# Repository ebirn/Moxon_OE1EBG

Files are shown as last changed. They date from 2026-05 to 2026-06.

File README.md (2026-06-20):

# Moxon antenna kit
by OE1EBG

## Interactive calculator



An interactive Jupyter notebook for Moxon rectangle dimensions and visualization is available at [`notebooks/interactive_moxon_calculator.ipynb`](notebooks/interactive_moxon_calculator.ipynb).

The notebook includes the theory note from [`notebooks/moxon_theory.md`](notebooks/moxon_theory.md), presets for 2 m and 70 cm, conductor diameter and velocity factor controls, dimension tables, and scaled geometry plots.

## Tuning guide

Structured build and tuning instructions are available in [`TUNING.md`](TUNING.md). The guide starts from the printed T-pieces, pipes, wire, and an antenna analyzer such as a NanoVNA or RigExpert Stick, then walks through iterative Moxon-specific tuning.

The tuning protocol notebook [`notebooks/moxon_tuning_protocol.ipynb`](notebooks/moxon_tuning_protocol.ipynb) provides a form for logging iterative measurements to CSV sessions under `notebooks/data/`. Notebook cell outputs are cleared by the repository hooks, so CSV files are the persistent tuning records and can be saved/restored independently.

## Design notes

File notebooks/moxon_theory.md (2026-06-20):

# Moxon Rectangle Antenna Theory

The Moxon rectangle is a compact, directional, two-element antenna invented by Les Moxon, G6XN. It behaves like a folded two-element Yagi: one element is driven from the feed line, and the second element is a parasitic reflector. The element ends are bent toward each other, so the antenna occupies less space than a straight two-element Yagi while retaining useful gain, a broad forward lobe, and a strong front-to-back ratio.

This kit is aimed mainly at the 70 cm and 2 m amateur radio bands. At those frequencies the dimensions are physically manageable, but small construction errors are also a larger fraction of a wavelength. That makes geometry, conductor diameter, feed layout, and mounting details important.

## Geometry

A conventional Moxon rectangle is described with five practical dimensions:

| Symbol | Meaning |
| --- | --- |
| `A` | Long horizontal span of the driven element side |
| `B` | Folded driven-element tail length at each end |
| `C` | Gap between the driven tail and reflector tail |
| `D` | Folded reflector tail length at each end |
| `E` | Spacing between the driven-element side and reflector side |

The driven element is split at the middle for the feed point. The reflector is continuous and is not electrically connected to the feed line. The close end coupling through the `C` gaps is what makes the Moxon different from a simple bent dipole and reflector pair.

## Build-kit H-frame

This kit uses two T-pieces to hold the antenna in an H-shaped frame. Four equal outer pipes support the driven-element and reflector wires, and one center pipe sets the distance between the driven element and reflector.

The notebook derives these mechanical pipe dimensions from the electrical Moxon dimensions:

```text
outer_pipe_length = A / 2 - radiator_pipe_offset
center_pipe_length = E - center_pipe_offset
```

The offsets account for socket depth, printed part geometry, wire attachment position, or any other mechanical distance between the pipe end and the actual electrical wire position. They are defined globally in the notebook as `RADIATOR_PIPE_OFFSET_MM` and `CENTER_PIPE_OFFSET_MM`, so a kit-specific value can be set once and reused for every frequency.

## Why the Moxon works

The driven element produces the primary radiation. The reflector is placed behind it and is slightly longer in effective electrical length. Because the reflector is parasitic, current is induced in it by the field from the driven element. The induced current has a phase relationship that reinforces radiation in the forward direction and cancels part of the radiation toward the rear.

In a straight two-element Yagi, the reflector is normally behind the driven element with an open air spacing. In the Moxon, the ends of both elements are folded toward each other. This changes the mutual coupling. The folded ends add capacitance and make the antenna shorter across the boom direction. The result is a compact rectangle with impedance often close enough to 50 ohms for direct coax feed when dimensions are chosen well.

## Electrical length and wavelength

The free-space wavelength is:

```text
lambda = c / f
```

where `c` is the speed of light and `f` is the design frequency. For quick radio work:

```text
lambda_m = 299.792458 / frequency_MHz
```

Real conductors do not behave exactly like infinitely thin wires in free space. Conductor diameter, insulation, bends, nearby plastic or metal, and the feed connection all shift resonance. A velocity factor can be used as a simple build correction, but final tuning should still be done by measurement.

## Feed-point impedance

A well-designed Moxon rectangle often lands near 50 ohms at resonance. This is one of the reasons it is popular for portable and kit antennas. The feed point is at the center of the driven element. A current choke or common-mode choke at the feed point is strongly recommended, especially for VHF/UHF, because coax shield current can distort the pattern and alter the match.

The exact feed impedance depends on:

| Factor | Effect |
| --- | --- |
| Driven/reflector spacing `E` | Strongly affects impedance and pattern |
| End gap `C` | Strongly affects coupling and front-to-back ratio |
| Conductor diameter | Changes electrical length and bandwidth |
| Feed gap and feed hardware | Adds capacitance and inductance at the driven element center |
| Mounting structure | Nearby metal or lossy material can detune the antenna |

## Pattern, gain, and front-to-back ratio

The forward gain of a practical Moxon is commonly in the same class as a small two-element beam. The main attraction is not maximum gain; it is the combination of compact size, broad pattern, useful gain, and high rear rejection. A carefully built Moxon can have a very good front-to-back ratio, which is useful when reducing interference or favoring one direction.

For satellite, portable, fox hunting, or local VHF/UHF work, the wider forward lobe can be more forgiving than a higher-gain narrow Yagi. For weak-signal terrestrial work, the lower boom length and compact frame are useful, but a longer Yagi will usually provide more gain.

## Polarization

The drawing in the notebook is a plan-view geometry. The polarization depends on how the finished rectangle is oriented. If the driven element is horizontal, the antenna is horizontally polarized. If the driven element is vertical, it is vertically polarized. Match the polarization to the intended use: FM repeaters are commonly vertical, while weak-signal SSB/CW operation is commonly horizontal.

## Tuning workflow

Use the notebook dimensions as a starting point, not as final guaranteed dimensions.

1. Choose the exact center frequency for the intended operating range.
2. Build the antenna symmetrically and keep the end gaps repeatable.
3. Use a short, mechanically stable feed connection at the driven element center.
4. Add a choke at the feed point.
5. Measure SWR or return loss in the intended installed orientation.
6. If resonance is low in frequency, shorten the driven element slightly.
7. If resonance is high in frequency, lengthen the driven element slightly.
8. Adjust the end gaps only carefully, because they affect both match and pattern.

## Limitations of the notebook calculator

The notebook uses practical proportional dimensions calibrated against typical online Moxon calculator output for 2 m and 70 cm examples. It is intended for visualization, kit documentation, and first-cut mechanical planning. For a production antenna or a critical build, validate the dimensions with a NEC model, a known calculator such as MoxGen/W4RNL-derived tools, and real VNA measurements.

## References

The notebook dimensions and explanations were cross-checked against these Moxon references and calculators:

| Reference | Notes |
| --- | --- |
| [W6BSD Moxon Antenna Calculator](https://0x9900.com/moxon-antenna-calculator/) | Online calculator used for the 145 MHz and 435 MHz reference screenshots in this repository. |
| [3G-aerial Moxon Antenna Calculator](https://3g-aerial.biz/en/online-calculations/antenna-calculations/moxon-antenna-calculator) | Online Moxon calculator with NEC/MMANA export; documents its W4RNL/Cebik and MoxGen-style basis. |
| [AC6LA MoxGen](http://www.ac6la.com/moxgen.html) | Classic Moxon Rectangle Generator by Dan Maguire, AC6LA, based on L. B. Cebik's algorithm. |
| [L. B. Cebik, W4RNL: The Moxon Rectangle: A Review](http://www.antentop.org/w4rnl.001/mox20.html) | Background article on Moxon rectangle behavior, geometry, and modeling. |
| [Moxon Antenna Project](https://moxonantennaproject.net/index.html) | Collection of Moxon antenna articles, dimensions, models, and practical builder examples. |
| [Moxon antenna overview](https://en.wikipedia.org/wiki/Moxon_antenna) | General overview and historical context for the Moxon rectangle. |

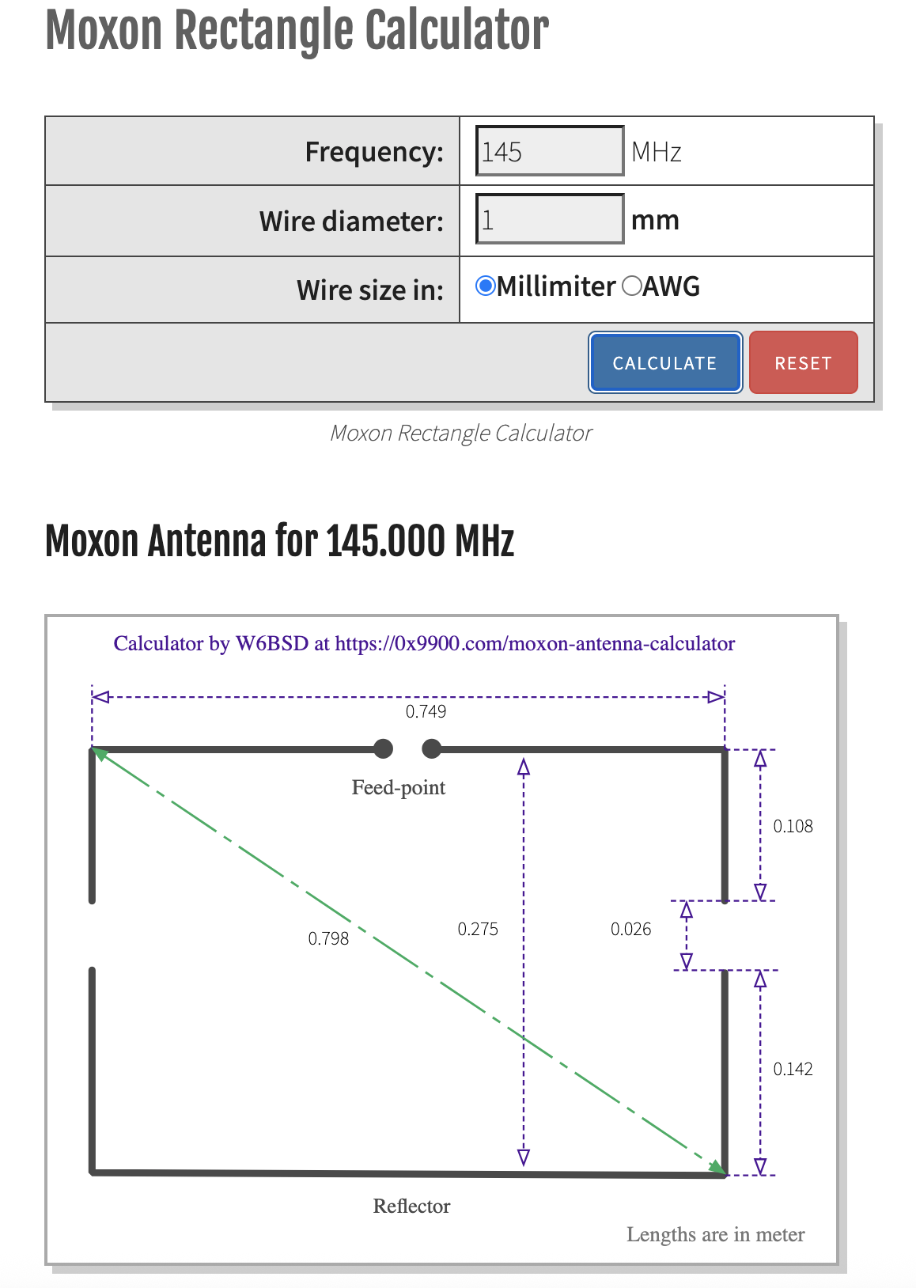
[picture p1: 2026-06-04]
img/Moxon_calculator_145MHz.png

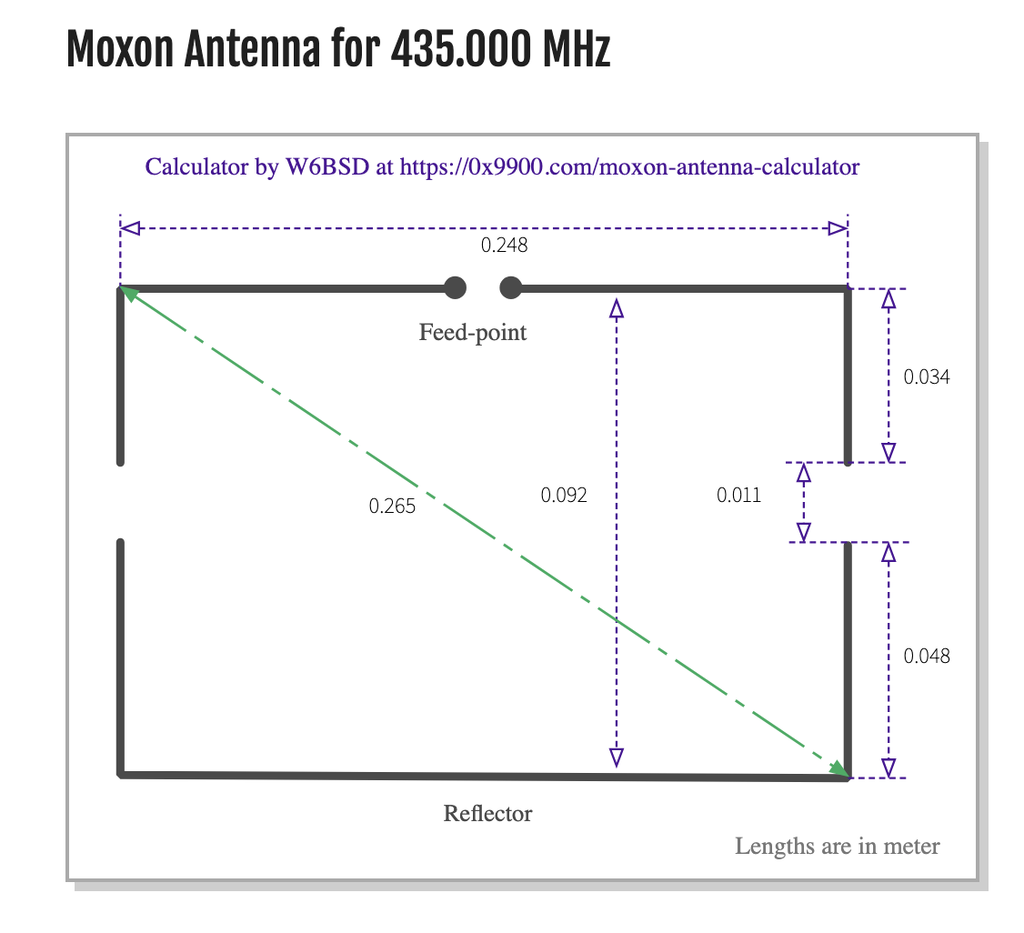
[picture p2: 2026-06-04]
img/Moxon_calculator_435MHz.png

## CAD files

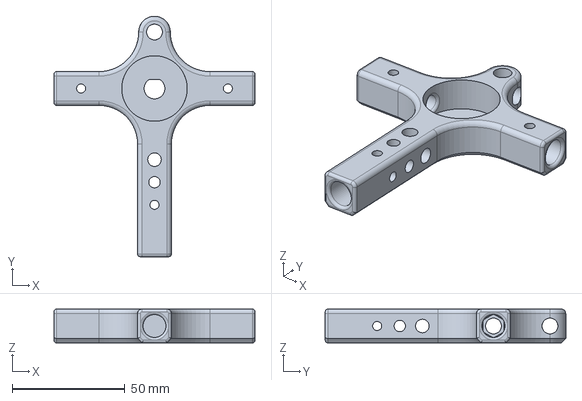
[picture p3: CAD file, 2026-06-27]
Moxon_OE1EBG.FCStd
89.0 x 106.5 x 15.0 mm

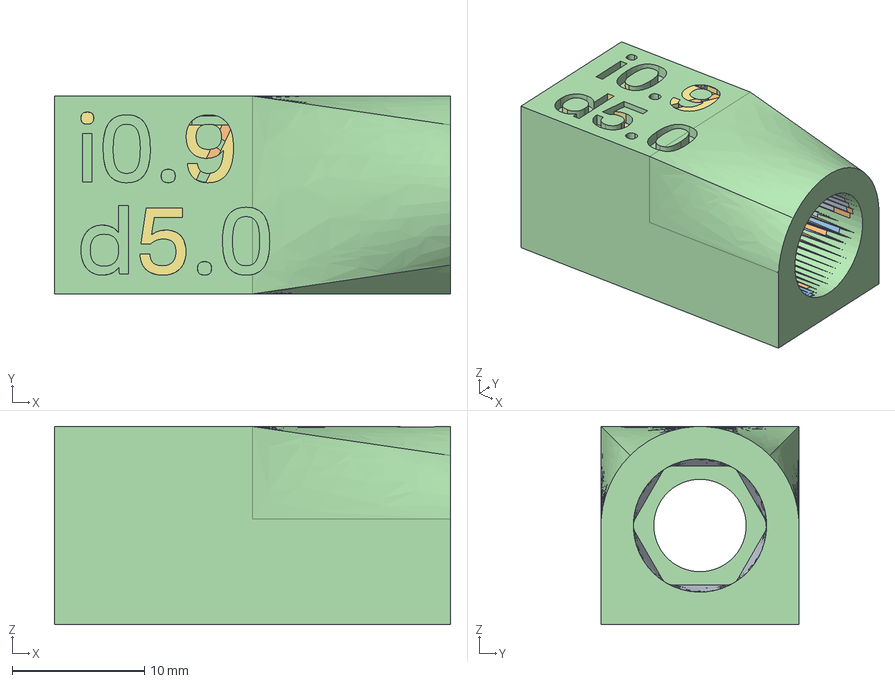
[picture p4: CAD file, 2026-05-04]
PipeRetainerVariants.FCStd
30.0 x 15.0 x 15.0 mm
PipeRetainerDemo
PipeRetainerDemo001
PipeRetainerDemo002
PipeRetainerDemo003
PipeRetainerDemo004
PipeRetainerDemo005
PipeRetainerDemo006
PipeRetainerDemo007

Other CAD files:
.freecad_tools/template_print_settings.3mf

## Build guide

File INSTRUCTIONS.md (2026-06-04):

# Moxon Antenna
 by OE1EBG

## Introduction
This is a Moxon antenna, which is a type of directional antenna that is compact and easy to build. It consists of two elements: a driven element and a reflector. The driven element is connected to the feedline, while the reflector is positioned behind it to enhance the antenna's gain and directivity.

## Moxon tuning
Calculator: https://0x9900.com/moxon-antenna-calculator/

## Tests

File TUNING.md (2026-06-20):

# Moxon Antenna Tuning Guide

This guide starts after the two printed T-pieces are available, the H-frame pipes are on hand, and enough wire is available for the driven element and reflector. It assumes a NanoVNA, RigExpert Stick, or similar 50 ohm antenna analyzer is available.

The goal is not only a low SWR. A Moxon rectangle is a coupled two-element antenna, so the final adjustment must preserve the geometry that gives the antenna its forward gain and rear null.

This guide has three layers:

1. **Theory** – how a Smith chart represents impedance and why an antenna's measured trace looks the way it does.
2. **Tooling** – how to set up a NanoVNA so the Smith chart actually shows the antenna, not the feed cable.
3. **Practice** – a step-by-step Moxon tuning procedure that reads the Smith chart at each step and ties it back to a specific dimension (`A`, `B`, `C`, `D`, `E`).

## Geometry Terms

Use the same dimension names as the calculator and theory note:

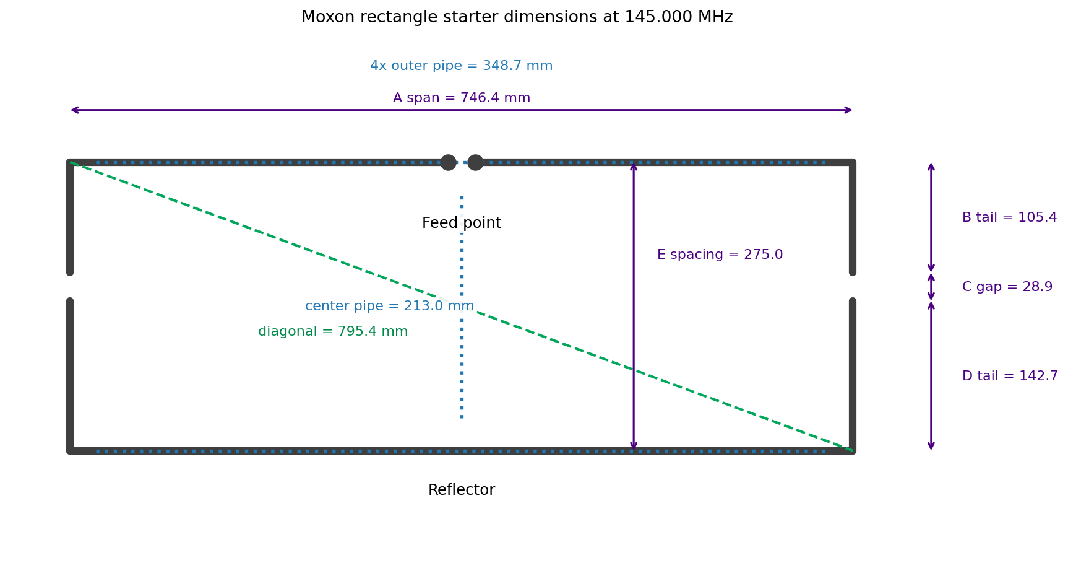
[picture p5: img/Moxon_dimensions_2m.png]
Moxon starter dimension diagram


The image shows the plan-view antenna geometry for a 145 MHz starter build. The exact values will change with frequency, conductor diameter, velocity factor, and final tuning, but the letters keep the same meaning.

| Symbol | Meaning | Tuning role |
| --- | --- | --- |
| `A` | Horizontal span of the long driven side and the long reflector side | The left-to-right rectangle width. In the image, this is the purple `A span` arrow across the top. |
| `B` | Driven-element folded tail length at each end | The short vertical driven tails that turn down from the top driven element. In the image, this is `B tail`. |
| `C` | End gap between the driven tail and reflector tail | The small open space between the two facing wire ends on each side. In the image, this is `C gap`. |
| `D` | Reflector folded tail length at each end | The short vertical reflector tails that turn up from the bottom reflector. In the image, this is `D tail`. |
| `E` | Spacing between the driven side and reflector side | The front-to-back spacing between the top driven element and bottom reflector. In the image, this is `E spacing`. |

The blue dotted lines in the image are the H-frame pipe cuts for this kit, not electrical Moxon dimensions. They are derived from `A` and `E` after subtracting the printed-part offsets. The green dashed diagonal is a useful mechanical check that the rectangle is square and repeatable.

The driven element is split at the feed point. The reflector is continuous. The two `C` gaps must be equal, and the left and right halves must stay symmetrical.

## What To Optimize

Tune in this order:

1. Mechanical symmetry and repeatable dimensions.
2. Feed-point resonance at the intended center frequency.
3. Feed-point impedance near 50 ohms without using coax length as a hidden matching element.
4. Stable SWR with the feed line moved by hand.
5. Best practical front-to-back ratio in the final mounting orientation.

For FM repeater use, choose a center frequency in the part of the band you actually use. For weak-signal SSB/CW or satellites, tune for that operating segment, not for the middle of the whole amateur band.

## Smith Chart Theory For Antenna Tuning

This section is the "why" behind every later instruction that says "watch the Smith chart". It is written so that the practical steps make sense even if you have never used a Smith chart before.

### Reflection coefficient and normalized impedance

Everything on the chart is a plot of the **reflection coefficient** `Γ` (gamma), a complex number that compares the impedance at the measurement point `Z` to the analyzer's reference impedance `Z0` (50 ohms for a NanoVNA):

```
Γ = (Z - Z0) / (Z + Z0)
```

`Γ` is what the analyzer actually measures (as a magnitude and phase, or as S11). Everything else — SWR, return loss, R, X — is computed from `Γ`.

- `Z = Z0` (perfect 50 ohm match) → `Γ = 0`, the exact center of the chart.
- `Z = 0` (short circuit) → `Γ = -1`, the leftmost point of the chart.
- `Z = ∞` (open circuit) → `Γ = +1`, the rightmost point of the chart.

The Smith chart is the unit disk of `Γ` (radius 1, center 0) with a grid drawn on it that lets you read `Z` directly instead of `Γ`. The grid is built from the **normalized impedance** `z = Z / Z0 = r + jx`, where `r` is normalized resistance and `x` is normalized reactance. For a 50 ohm system, `z = 1` corresponds to 50 ohms.

### Reading the chart: resistance circles, reactance arcs, and the unit circle

- **Constant-resistance circles** (`r = const`) are circles that all pass through the open-circuit point at the right edge (`Γ = +1`). The `r = 1` circle (50 ohms) passes through the exact center of the chart. Larger `r` values are smaller circles closer to the right edge; `r = 0` is the entire outer unit circle.
- **Constant-reactance arcs** (`x = const`) are arcs that also all converge at the open-circuit point on the right edge. Arcs in the **upper half** of the chart are positive reactance (`x > 0`, **inductive**). Arcs in the **lower half** are negative reactance (`x < 0`, **capacitive**). The horizontal centerline itself is `x = 0` — purely resistive.
- The **outer unit circle** (`|Γ| = 1`) represents a perfect open or short — all the power is reflected, `r = 0`.
- The **center point** is `z = 1 + j0`, i.e. `50 + j0 ohms`, a perfect match to the analyzer.

To read an impedance from a marker, find which resistance circle the point sits on (read `r`, multiply by 50 for ohms) and which reactance arc it sits on (read `x`, multiply by 50 for ohms, and note whether it is above the centerline → `+jX` inductive, or below → `-jX` capacitive).

### SWR circles and the matched point

A circle centered on the chart's center point, of radius `|Γ|`, is a **constant-SWR circle**. Every impedance on that circle gives the same SWR, because SWR depends only on `|Γ|`:

```
SWR = (1 + |Γ|) / (1 - |Γ|)
```

A `1.5:1` SWR circle is a specific, fairly small circle around the center. The whole point of antenna tuning is to get the impedance trace, at the frequencies you care about, **inside that circle** — it does not have to sit exactly on the center point.

This is the key distinction that the SWR-only view hides: **resonance** (where `X = 0`, the trace crosses the horizontal centerline) and **match** (where the trace is close to the center, inside the target SWR circle) are related but not identical. A Moxon can be "resonant" at a frequency where `R` is, say, 30 ohms and `X = 0` — that crossing is on the centerline but well outside the 50 ohm point, so SWR is not at its best there. The Smith chart shows you both facts at once; the SWR plot alone only shows you the second.

### Why the trace moves: frequency sweeps and antenna resonance

When the NanoVNA sweeps frequency, it draws a **trace** — a sequence of `Γ` points, one per frequency — on the chart. For an antenna near its design frequency, this trace is typically a small loop or arc, not a single point.

A useful mental model, true for the Moxon's driven element as for a simple dipole:

- Below the antenna's natural resonant frequency, the element is **electrically too short** for that frequency → the feedpoint reactance is **capacitive** (`X < 0`, trace below the centerline).
- Above the natural resonant frequency, the element is **electrically too long** → the feedpoint reactance is **inductive** (`X > 0`, trace above the centerline).
- At resonance, `X = 0` and the trace crosses the horizontal centerline.

As frequency increases across a sweep, the trace for a simple resonant element generally moves in a loop, crossing the centerline once near the resistive minimum (the usable "series resonance" most builders tune for). Where that crossing sits relative to the `r = 1` (50 ohm) circle tells you immediately whether you are dealing with a length problem (crossing at the wrong frequency) or a resistance problem (crossing at the right frequency, but on the wrong resistance circle).

For the Moxon specifically, the coupled driven element + reflector behave like a single resonator at the feedpoint. A well-built Moxon at its design frequency shows the trace passing close to the chart center — close to `50 + j0 ohms` — with the centerline crossing close to the design frequency marker.

### Cable length, phase rotation, and why reference plane matters

Adding a length of transmission line between the analyzer and the antenna **rotates** the trace around the chart center without changing its size (its SWR circle stays the same — lossless line does not change SWR, only where on the SWR circle the impedance appears). One full rotation around the chart corresponds to one half-wavelength of line.

This matters because:

- A trace that looks "rotated" or "smeared" compared to what theory predicts is often just **uncalibrated cable length**, not a bad antenna.
- The same antenna measured through 0.5 m vs 5 m of coax can show very different `R + jX` numbers at the same frequency, even though the antenna itself has not changed.
- Calibration must be done **at the connector where the antenna feed line attaches**, so the reference plane (the point where `Γ = 0` means "50 ohms here") is at the antenna, not at the analyzer's own SMA port.

If you must measure through a longer cable than you calibrated with, the NanoVNA's **electrical delay** (sometimes called port extension or cable length compensation) can rotate the displayed trace back to the antenna's reference plane, by entering the cable's electrical length (physical length × velocity factor). This is covered in the next section.

### Putting it together: what a "good" Moxon trace looks like

For this kit, at the chosen center frequency, the practical target is:

- The trace crosses (or nearly crosses) the horizontal centerline (`X ≈ 0`) close to the marker for the target frequency.
- At that crossing, the trace is close to the `r = 1` circle (50 ohms) — ideally inside the `1.5:1` SWR circle around the center.
- The loop is smooth and repeatable when the antenna or cable is touched — a jumpy, erratic trace usually means a common-mode or connector problem (see [Feed Point And Choke Checks](#feed-point-and-choke-checks)), not a geometry problem.

Everything from here on is about moving that crossing point to the right frequency (driven element length, `B`/tails) and onto the right resistance circle (`C` gap, `E` spacing) without breaking the reflector relationship that gives the antenna its front-to-back ratio (`D`).

## Using The Smith Chart On A NanoVNA

This section covers the practical NanoVNA setup needed before any of the readings above are meaningful.

### Calibration at the right reference plane

1. Decide on the short jumper cable (and any adapter) that will permanently sit between the NanoVNA and the antenna feed point during tuning.
2. Set the sweep range first (see below) — calibration is frequency-range specific on the NanoVNA.
3. From the calibration menu, step through **Open**, **Short**, and **Load** standards connected at the **far end of that jumper/adapter** — i.e. at the point that will actually plug into the antenna. This far end becomes `Γ = 0`'s reference plane.
4. Save the calibration to a calibration slot so it can be reloaded without repeating OSL every session.
5. Reconnect the 50 ohm load at the same point and confirm `SWR ≈ 1.0:1` and `Z ≈ 50 + j0 ohms` across the whole sweep. If this fails, the rest of the session's readings cannot be trusted — fix cables, adapters, or redo calibration before continuing.

Calibrating at the analyzer's own port and then adding the jumper cable afterwards reintroduces the cable-rotation problem from the theory section above. Always calibrate at the plane where the antenna will connect.

### Sweep setup and display format

1. Set **Start** and **Stop** frequencies to a narrow span around the target band, not a wide general-coverage sweep. For 2 m, `140–150 MHz` is a good starting span; for 70 cm, `420–450 MHz` or narrower if the operating segment is known.
2. Use enough sweep points that the trace near resonance is smooth (the NanoVNA default of 101 points is usually fine for a 10 MHz span on 2 m).
3. Set up at least two trace displays:
   - One trace in **SWR** format — gives the quick "is it getting better or worse" view during iterative trimming.
   - One trace in **Smith chart** format — gives the `R + jX` diagnosis described in the theory section.
4. Optionally add a third trace in **|Z| / phase** or **LogMag (return loss)** format if the firmware supports it; these are not required but can help confirm a reading.
5. Turn off traces you are not using. A screen with one SWR trace and one Smith chart trace, each with a marker on the target frequency, is enough for all of the steps below.

### Markers and electrical delay / port extension

1. Place a marker at the target operating frequency. This marker's `R + jX` readout is the number you write into the tuning log.
2. Place a second marker at the frequency of the SWR minimum (`f_min_swr`). Comparing the two marker positions tells you immediately whether the antenna is resonant at the wrong frequency (markers at different frequencies but both near the centerline) or resonant at the right frequency but poorly matched (markers near the same frequency, but `R` far from 50 ohms).
3. If the jumper cable used for tuning is longer than the one used for calibration (for example, measuring on a mast through a longer feed line than the bench jumper), use the **electrical delay** / port extension setting to rotate the trace back to the antenna terminals. Enter the extra cable's electrical length (physical length divided by velocity factor, converted to a time delay) until a known reference (e.g. a 50 ohm load at the antenna end) reads `50 + j0` again.
4. Re-zero or remove any electrical delay before going back to the calibrated bench jumper, or all subsequent readings will be rotated by that amount.

### Time-domain check for feed line issues

If the trace looks erratic, shows multiple loops, or does not match expectations even after calibration:

1. Switch to the NanoVNA's time-domain / TDR (time domain reflectometry) mode if available (often a "transform" or "TDR" function operating on the Smith chart or S11 data).
2. Look for reflections at distances other than zero and the expected antenna length — these indicate bad connectors, kinks, water ingress, or an incorrect cable velocity factor.
3. Resolve feed-line issues before trusting any Smith chart reading for geometry tuning. A damaged feed line will move the trace in ways that look like a geometry problem but are not.

### Reading the live trace while tuning

While trimming the antenna:

1. Watch the **Smith chart trace** move as you make a change, not just the SWR number.
2. A driven-element length change should move the centerline crossing **along the frequency axis** (the loop shifts left/right in frequency) without changing its basic shape much.
3. A `C` gap or `E` spacing change should move the trace **toward or away from the center** (changing which resistance circle it sits on) more than it shifts the centerline crossing in frequency.
4. If a change does something unexpected — e.g. the trace jumps wildly, reverses direction, or stops looking like a smooth loop — suspect a connection problem, a broken symmetry (one side trimmed differently from the other), or common-mode coupling before assuming the dimension itself is wrong.

## Tools And Setup

Use these items before cutting anything permanently:

| Item | Use |
| --- | --- |
| NanoVNA, RigExpert Stick, or similar analyzer | Measure S11, SWR, return loss, impedance, Smith chart trace, and resonant frequency |
| Short 50 ohm coax jumper | Connect the analyzer to the antenna feed point — this is the calibration reference plane |
| Open/short/load calibration standards | Calibrate the analyzer at the end of the measurement cable |
| 50 ohm dummy load | Quick sanity check for the analyzer and coax, and for electrical delay setup |
| Ruler or calipers | Measure `C`, `E`, and wire lengths repeatably |
| Masking tape or heat-shrink markers | Mark the as-built wire positions before trimming |
| Small cable ties or clamps | Temporarily hold wire tails during tuning |
| Ferrite choke or several ferrite beads | Suppress common-mode current on the feed line |
| Low-power transmitter or receiver | Optional field check of front-to-back behavior |

## First Mechanical Build

1. Choose the exact center frequency.
2. Use the calculator to get `A`, `B`, `C`, `D`, and `E` for the actual wire diameter and insulation state.
3. If the wire is insulated, expect the real antenna to be electrically longer than a bare-wire calculation.
4. Assemble the two T-pieces and pipes into the H-frame.
5. Set the center pipe so the driven side and reflector side are separated by `E` at the wire positions, not just at the plastic or pipe centerline.
6. Cut the driven wire slightly long, with enough spare at each end to form the `B` tails and allow small trimming.
7. Cut the reflector wire slightly long, with enough spare at each end to form the `D` tails and allow small trimming.
8. Install the reflector as one continuous wire.
9. Install the driven element as two equal halves with a small feed gap at the center.
10. Make the feed-point leads short and symmetrical.
11. Set both `C` gaps to the calculator value.
12. Make the left-side `C` gap and right-side `C` gap as equal as possible.
13. Add a 1:1 current choke at the feed point or immediately below it.
14. Route the feed line away from the driven element at right angles for at least a short distance before it turns toward the operator or mast.

The first build should be adjustable. Do not solder, glue, or permanently crimp the final wire tails until the antenna has been measured in the intended orientation.

## Measurement Position

Measure the antenna in the same polarization and as close as practical to the intended operating setup.

1. Keep the antenna away from metal benches, cars, railings, gutters, tripods, and the operator's body.
2. For 2 m, try to keep people and metal at least `1 m` away during measurements.
3. For 70 cm, try to keep people and metal at least `0.5 m` away during measurements.
4. Hold or mount the antenna so the frame is not touching conductive objects.
5. Keep the analyzer behind or below the antenna, not inside the rectangle.
6. Do not let the coax run parallel along the driven element or reflector.

The exact height above ground changes the reading. That is normal. Tune at the height and mounting style that will actually be used when possible.

## First Sweep

Record these values before changing anything:

| Value | What to record |
| --- | --- |
| `f_min_swr` | Frequency where SWR is lowest |
| `SWR_min` | Lowest SWR value |
| `R` at target frequency | Resistive part of impedance |
| `X` at target frequency | Reactive part of impedance |
| `SWR` at target frequency | Match at the chosen operating frequency |
| `C_left` and `C_right` | Actual end gaps |
| `E` | Actual driven-to-reflector spacing |

Read the Smith chart trace as described above:

- Find where the trace crosses the horizontal centerline (`X = 0`). Compare that frequency to the target frequency and to `f_min_swr`.
- Note which resistance circle the trace is on at the target frequency marker — is it inside, on, or outside the `r = 1` (50 ohm) circle?
- Note whether the target-frequency point is above the centerline (inductive, element electrically long) or below it (capacitive, element electrically short).

These three observations are exactly the inputs the tuning steps below ask for.

## How Geometry Maps To The Smith Chart Trace

Before trimming anything, it helps to know what each dimension does to the trace. This table summarizes the practical effect of each Moxon dimension on the Smith chart, based on general dipole/parasitic-array behavior and Moxon-specific build notes (see References).

| Dimension | Primary Smith chart effect | Secondary effect |
| --- | --- | --- |
| `B` (driven tail length) — and overall driven element length | Shifts the centerline (`X = 0`) crossing along the frequency axis. Shorter → crossing moves up in frequency and the target-frequency point becomes more capacitive (moves below centerline). Longer → crossing moves down in frequency and the point becomes more inductive (moves above centerline). | Small effect on `R` at resonance |
| `C` (end gap, driven-to-reflector tail spacing) | Changes the coupling between driven and reflector tails, which mainly changes which resistance circle the trace sits on at resonance (moves the trace toward or away from the `r = 1` / 50 ohm circle) and the size/shape of the loop. | Can also shift the centerline crossing slightly; re-check resonance after changing `C` |
| `E` (driven-to-reflector spacing) | Changes the overall resistance level of the trace (shifts which resistance circle the loop sits on), and reshapes the loop. | Affects the radiation pattern together with `R`; do not use as the first correction for a frequency error |
| `D` (reflector tail length) | Small direct effect on the feedpoint trace; its main job is front-to-back ratio, not match. | Can interact with `C` and `E` at the margins |
| `A` (overall span) | Sets the overall scale of the design; in practice this kit treats `A` as fixed by the calculator and the H-frame, not as a field-tuning control. | — |

In short: **`B` (driven length) moves the loop left/right in frequency. `C` and `E` move the loop toward/away from the chart center (the resistance value). `D` is mostly about the pattern, not the trace.**

## Main Tuning Rule

Tune the driven element first.

| Symptom (SWR view) | Smith chart confirmation | Likely cause | First correction |
| --- | --- | --- | --- |
| SWR dip is below the target frequency | Centerline crossing is below the target frequency; target-frequency point sits above the centerline (inductive) | Driven element is electrically too long | Shorten both driven halves equally |
| SWR dip is above the target frequency | Centerline crossing is above the target frequency; target-frequency point sits below the centerline (capacitive) | Driven element is electrically too short | Lengthen both driven halves equally if possible |
| SWR dip is near target but minimum SWR is not good | Centerline crossing is near the target frequency, but the trace there is on a resistance circle far from `r = 1` (50 ohms) | Coupling or feed impedance issue | Adjust `C`, then check `E` only if needed |
| Reading changes when the coax is moved | Trace shifts or becomes erratic/jumpy when the cable is touched | Common-mode current or feed-line coupling | Improve choke and feed-line routing before trimming |
| One side tunes differently from the other | Trace behaves inconsistently between repeated measurements at the same nominal settings | Asymmetry | Re-measure `B`, `C`, `D`, feed gap, and wire routing |

For an antenna that was intentionally built slightly long, the normal path is to trim upward in frequency. Trim in small equal steps and re-measure after every change.

## Driven Element Length Adjustment

The driven element controls resonance most directly — on the Smith chart, it controls **where the trace crosses the centerline (`X = 0`)**.

1. Read the Smith chart at the target frequency. If the point sits **above** the centerline (positive `X`, inductive), the element is electrically too long for this frequency.
2. If the point sits **below** the centerline (negative `X`, capacitive), the element is electrically too short.
3. If the SWR minimum is below the target frequency (centerline crossing too low in frequency, target point inductive), mark both driven tails.
4. Shorten the driven element by the same amount on both ends.
5. Start with very small cuts.
6. For 2 m, use steps of about `2 mm` to `5 mm` per driven end.
7. For 70 cm, use steps of about `0.5 mm` to `2 mm` per driven end.
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

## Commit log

2026-03-26 Moxon project: initial commit
    [Moxon_OE1EBG.FCStd]
2026-03-26 initial version of main connector piece
    [Moxon_OE1EBG.FCStd]
2026-03-26 cover: for BNC connector body, initial design
    [Moxon_OE1EBG.FCStd]
2026-03-26 first prototype version
    [Moxon_OE1EBG.FCStd]
2026-03-29 add rounded angle connector, add grooves to cover
    [Moxon_OE1EBG.FCStd]
2026-03-29 added Assembly of all parts
    [Moxon_OE1EBG.FCStd]
2026-03-29 add embossing to cover
    [Moxon_OE1EBG.FCStd]
2026-03-29 add notch to pipe holder in feed part
    [Moxon_OE1EBG.FCStd]
2026-03-29 check whole Assembly
    [Moxon_OE1EBG.FCStd]
2026-03-30 cleanup Feed base geometry
    [Moxon_OE1EBG.FCStd]
2026-03-30 cleanup retaining ribs in feed part
    [Moxon_OE1EBG.FCStd]
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2026-03-31 add template pipe holder
    [Moxon_OE1EBG.FCStd]
2026-04-02 cleanup Feed body
    [Moxon_OE1EBG.FCStd]
2026-04-02 retention notch for rounded angle
    [Moxon_OE1EBG.FCStd]
2026-04-02 fixup cover sizing
    [Moxon_OE1EBG.FCStd]
2026-04-02 add strengthening bar for rounded angle
    [Moxon_OE1EBG.FCStd]
2026-04-03 cleanup mounting holes on feed part
    [Moxon_OE1EBG.FCStd]
2026-04-03 before refactor Feed main body
    [Moxon_OE1EBG.FCStd]
2026-04-03 cleanup Feed Body before round arm refactor
    [Moxon_OE1EBG.FCStd]
2026-04-03 round angle: longer cross bar
    [Moxon_OE1EBG.FCStd]
2026-04-03 major Feed body refactor, rounded pipe arms
    [Moxon_OE1EBG.FCStd]
2026-04-05 fixup BNC connector hole
    [Moxon_OE1EBG.FCStd]
2026-04-05 Feed mostly cleanup geometry
    [Moxon_OE1EBG.FCStd]
2026-04-05 fixup: almost all fillets
    [Moxon_OE1EBG.FCStd]
2026-04-06 Feed body complete cleanup, fixing fillets and align with other parts
    [Moxon_OE1EBG.FCStd]
2026-04-06 protptype printing
    [Moxon_OE1EBG-Angle_Round_1notch.3mf, Moxon_OE1EBG-Angle_Round_no_notch.3mf, Moxon_OE1EBG-Cover.3mf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]
2026-04-10 add holes in angle, add license info CC-BY-SA-4.0
    [Moxon_OE1EBG.FCStd]
2026-04-12 fixup round angle for multiple notches
    [Moxon_OE1EBG.FCStd]
2026-04-13 feed: simplify chamfer, new: PiperRetainerDemo
    [Moxon_OE1EBG.FCStd]
2026-04-14 prepare retainer variants testing
    [Moxon_OE1EBG.FCStd]
2026-04-15 use spreadsheet for variant config data
    [Moxon_OE1EBG.FCStd]
2026-04-15 add macro to auto assign config variants from spreadsheet
    [Moxon_OE1EBG.FCStd]
2026-04-16 refactor angle to hex retainers
    [Moxon_OE1EBG.FCStd]
2026-04-19 Feed: improve fit of BNC connector (thighter) Angle: make mount holes 5mm
    [Moxon_OE1EBG.FCStd]
2026-04-19 add pipes for assembly
    [Moxon_OE1EBG.FCStd]
2026-04-19 Assembly: modeled all joints, add exploded view
    [Moxon_OE1EBG.FCStd]
2026-04-20 add Techdraw with dimensions ("broken view" style)
    [Moxon_OE1EBG.FCStd]
2026-04-20 tuning techdraw
    [Moxon_OE1EBG.FCStd]
2026-04-22 increase and parameterize font size in variant array
    [Moxon_OE1EBG.FCStd]
2026-04-25 cleanup after tools refactor
    [Moxon_OE1EBG-Angle_Round_1notch.3mf, Moxon_OE1EBG-Angle_Round_no_notch.3mf, Moxon_OE1EBG-Cover.3mf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]
2026-04-25 chore: update freecad_tools reference to latest commit
    [template_print_settings.3mf]
2026-04-25 setup export config
    [Moxon_OE1EBG.FCStd]
2026-05-03 integrating workflows
    [PipeRetainerVariants.FCStd]
2026-05-04 add macro config, include INSTRUCTIONS in asset bundle
    [PipeRetainerVariants.FCStd]
2026-05-12 try cleanup broken view, object is now offset/wrapped around in the view
    [Moxon_OE1EBG.FCStd]
2026-05-14 cleanup techdraw for clearer dimensions and break lines
    [Moxon_OE1EBG.FCStd]
2026-05-14 setup pipe retainer 5mm depth, 0,5 roundness
    [Moxon_OE1EBG.FCStd]
2026-05-14 update template with perimeter and seam settings
    [template_print_settings.3mf]
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2026-06-04 major cleanup, Assembly with Round corners
    [Moxon_OE1EBG.FCStd]
2026-06-04 cleanup BackT Assembly
    [Moxon_OE1EBG.FCStd]
2026-06-04 tech draw for BackT variant
    [Moxon_OE1EBG.FCStd]
2026-06-04 add callsign label to BackT part
    [Moxon_OE1EBG.FCStd]
2026-06-04 improved chamfer/fillet top bottom and side
    [Moxon_OE1EBG.FCStd]
2026-06-04 add calculator info
    [Moxon_OE1EBG.FCStd]
2026-06-04 update length measures for 430MHz
    [Moxon_OE1EBG.FCStd]
2026-06-04 improve back pipe cut sketch
    [Moxon_OE1EBG.FCStd]
2026-06-04 simplyfy geometry more, simplify chamfer/fillet again
    [Moxon_OE1EBG.FCStd]
2026-06-04 corrected dimensions for 2m version
    [Moxon_OE1EBG.FCStd]
2026-06-04 Assemblies need more work for export and bom
    [Moxon_OE1EBG.FCStd]
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2026-06-20 Update FreeCAD dimensions from calculator
    [Moxon_OE1EBG.FCStd]
2026-06-20 Add Moxon tuning protocol notebook
    [moxon_tuning_log.csv]
2026-06-20 docs(tuning): add Smith chart theory and NanoVNA tuning workflow
    Expand TUNING.md with reflection coefficient/Smith chart fundamentals,
    a practical NanoVNA calibration and reading workflow, and a geometry-to-trace
    mapping table, then weave Smith chart readings into the existing
    step-by-step Moxon tuning procedure and references.
2026-06-20 parameterize connector hole
    [Moxon_OE1EBG.FCStd]
2026-06-22 resize dimensions for SO239 connector hole (tolerance)
    [Moxon_OE1EBG.FCStd]
2026-06-23 add Mast adapter for wider mast tops
    [Moxon_OE1EBG.FCStd]
2026-06-24 fix orientation of mast holes vs Antenna holder
    [Moxon_OE1EBG.FCStd]
2026-06-27 fix font size on mast adapter, increase SO239 hole diameter
    [Moxon_OE1EBG.FCStd]
2026-08-11 Add NEC2 export section to Moxon calculator notebook
    Generates a free-space NEC2 card deck (GW/EX/FR/RP) from the current
    geometry for validation in nec2c/4nec2/EZNEC before building.
2026-08-11 Allow overriding NEC export dimensions with measured values
    Adds per-side B/D tail overrides (matching the tuning log's CSV
    columns) plus a live labeled diagram so measured or as-built
    antennas can be exported accurately, not just calculator output.
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2026-08-11 Add vertical polarization option to NEC export
    Refactors moxon_nec_wires to build the flat rectangle first and then
    place it per a polarization parameter: horizontal (unchanged) lays it
    flat at the mounting height, vertical rotates it 90 degrees about the
    boom so elements run vertically with Height m meaning the boom/feed
    height. Adds a Polarization dropdown and a ground-clearance warning
    for low heights in vertical mode; moxon_nec_deck's height comment now
    reports a Z range instead of assuming a constant height.
2026-08-11 Add notebook dry-run checks (pre-commit hook and CI job)
    Executes every staged/pushed notebook with nbconvert and fails if any
    cell raises, catching widget-wiring/runtime errors that the existing
    output-clearing hook wouldn't notice - locally via a new pre-commit
    hook, and in CI via a new notebook-dry-run job that installs the
    project with uv first.
2026-08-11 Pin CI actions to commit SHAs instead of version tags
    Tags can be moved to point at a different commit; SHAs can't. Pinned
    actions/checkout and astral-sh/setup-uv to their commit SHAs (resolved
    via the GitHub API), using the latest releases that target Node 24
    since GitHub Actions runners now force older Node 20 actions onto
    Node 24 anyway, with a deprecation warning. Kept the version as a
    trailing comment for readability.
2026-08-11 Retry notebook execution on failure instead of chasing a higher timeout
    The current commit on this branch just failed one CI run at 908s,
    exceeding the 900s per-cell timeout - confirming the observed runner
    variance can occasionally cross any fixed threshold. Retrying the
    whole notebook up to 3 times handles this far more robustly than an
    ever-higher timeout, since a merely-slow run still succeeds quickly
    on a subsequent attempt.
